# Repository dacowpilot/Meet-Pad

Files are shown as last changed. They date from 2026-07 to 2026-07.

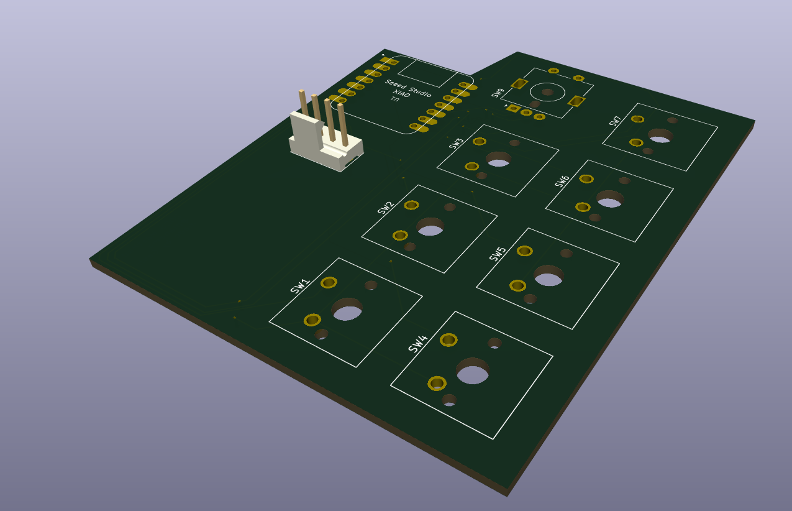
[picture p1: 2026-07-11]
Assets/PCB-3d-rendering.png

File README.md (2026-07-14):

# Meet-Pad
_com apple Pasteboard bxIFWW  
made in Shapr3D
# Features 

Meet-Pad is a hackpad that has 7 keys for shortcuts(like mute, camera, record, leave, etc.), a rotary encoder for volume control, and an OLED display screen for things like status. Like the name says, it will be used for shortcuts in meetings such as zoom calls and other meeting apps. The firmware might have a few bugs right now but I can fix it later once I get the XIAO.

# CAD

_com apple Pasteboard 4OdL4Z
_com apple Pasteboard 09b4Jj
Made in Shapr3D.

# PCB

PNG image
PNG image  

Made in KiCad.

# BOM

I already have a soldering iron so I don't need the soldering grant, but I do need the PCB and 3D printed case grant.  

Below are the parts I will be using to make my hackpad:  

• 1x XIAO RP2040  
• 7x Cherry MX Switches  
• 1x EC11 Rotary Encoder  
• 1x 0.91 inch OLED display  
• 7x White DSA Keycaps  
• 4x M3x16mm screws  
• 1x 3D printed case (1x Top Piece, 1x Bottom Piece, 1x Rotary Encoder Knob)
• 1x PCB board

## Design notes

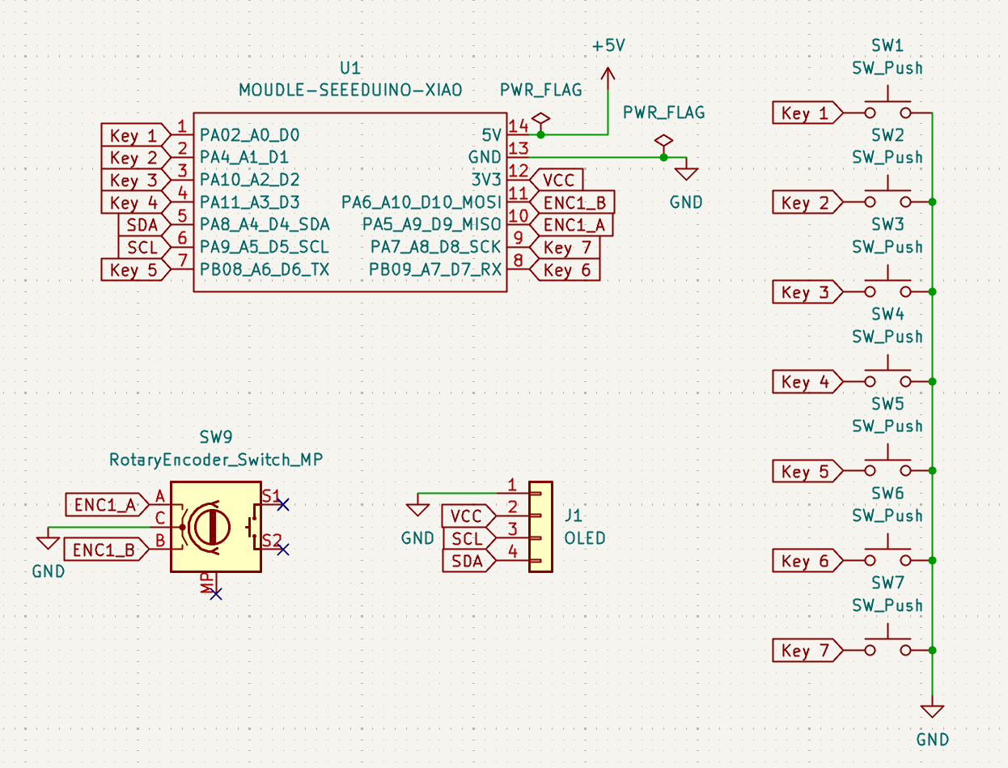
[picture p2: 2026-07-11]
Assets/schematic.png

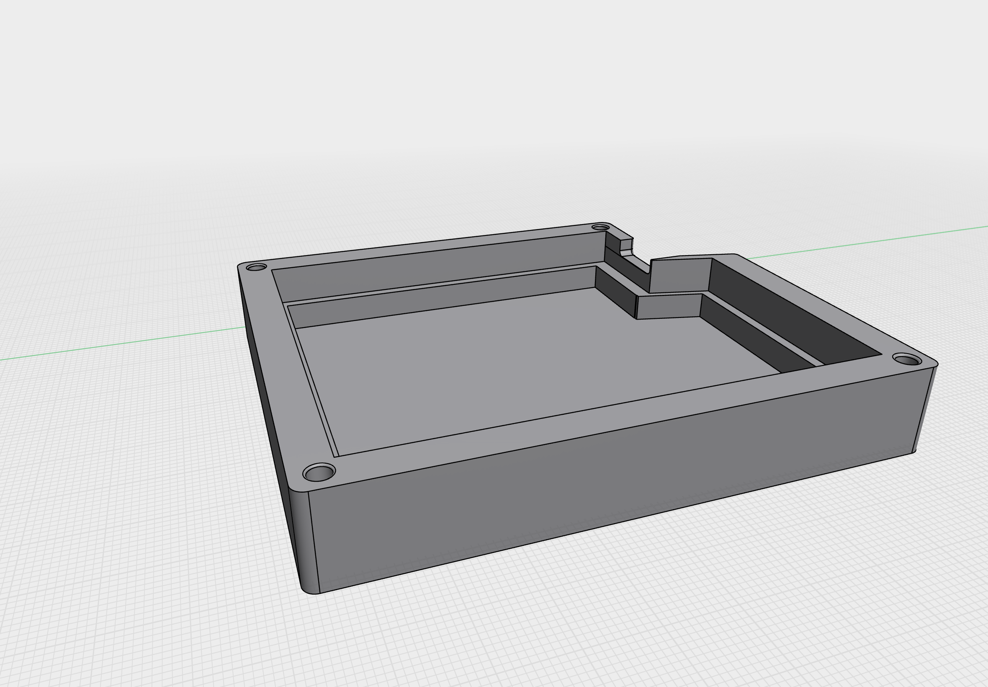
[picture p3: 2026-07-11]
Assets/case-bottom.png

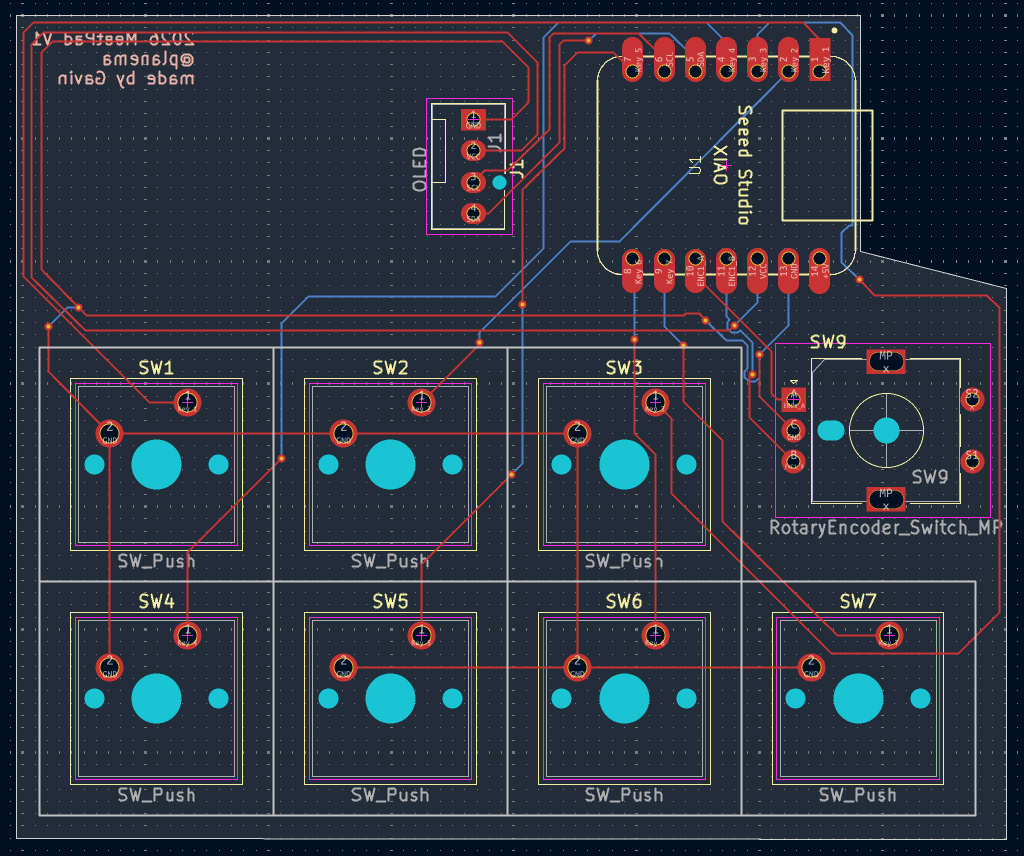
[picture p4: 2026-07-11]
Assets/PCB.png

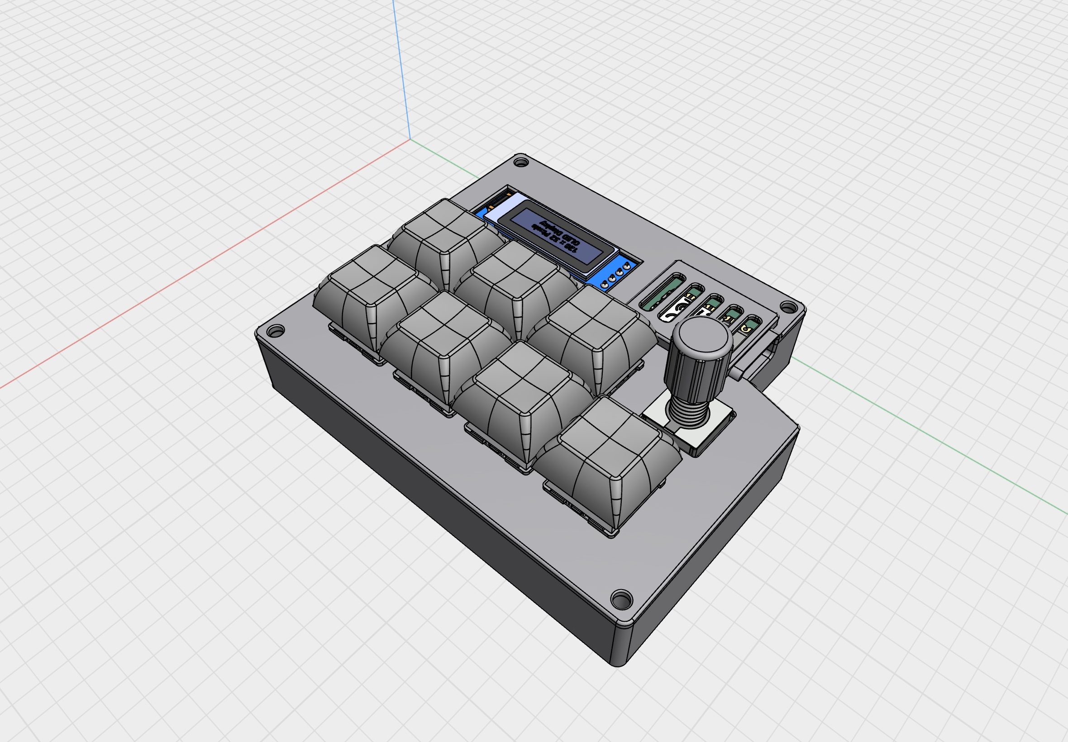
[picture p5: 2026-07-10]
Assets/Meetpad.png

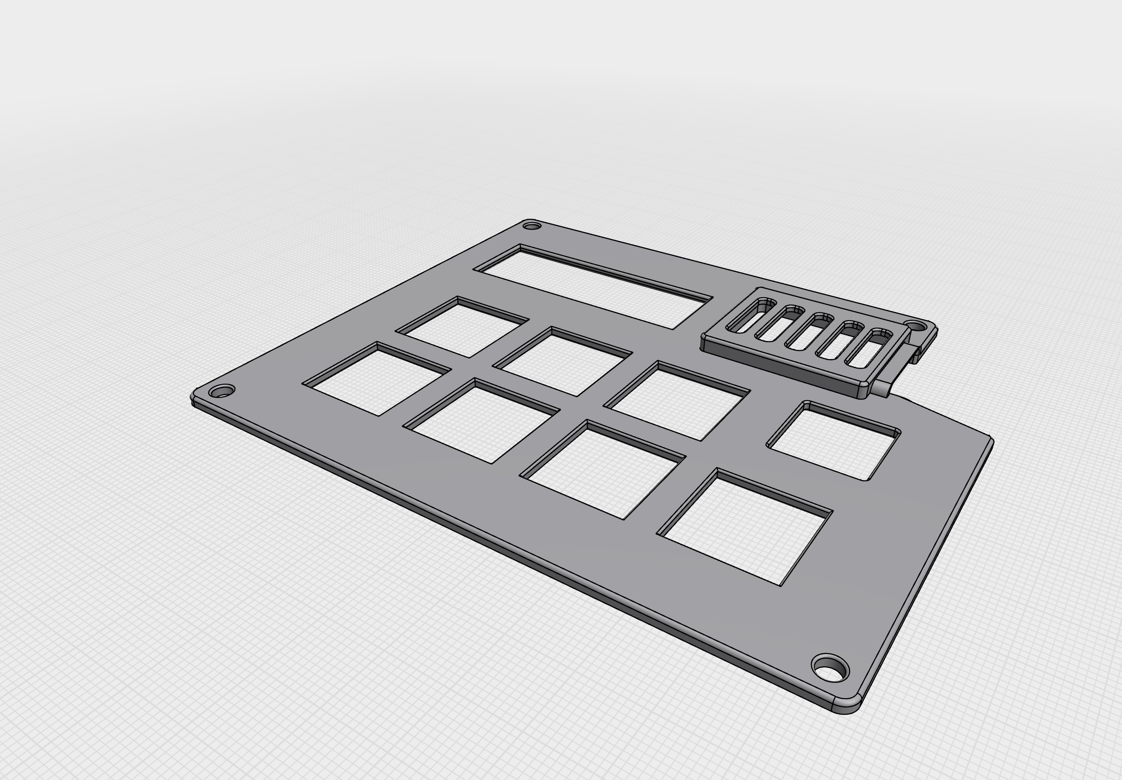
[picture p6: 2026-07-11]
Assets/top-case.png

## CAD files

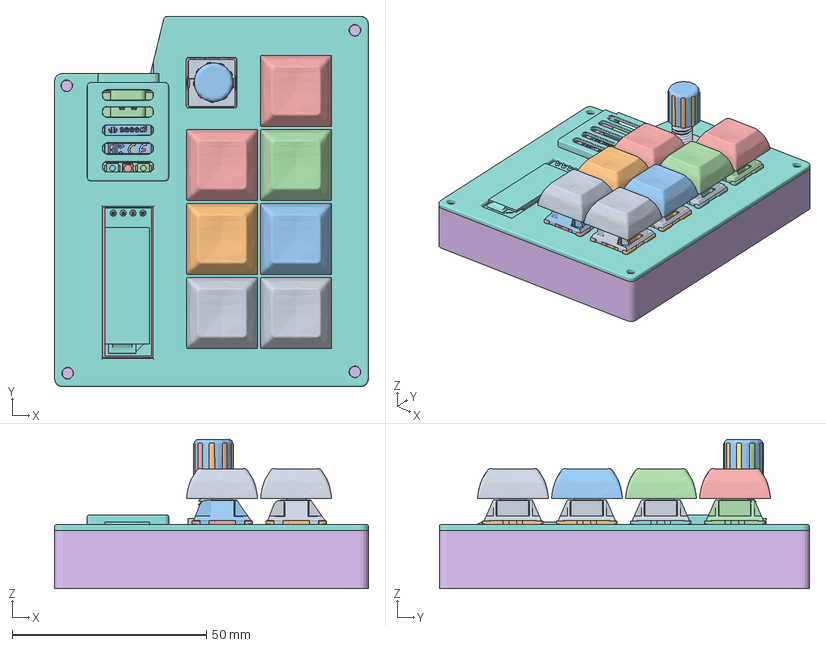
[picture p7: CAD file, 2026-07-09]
CAD/meetpad.3mf
80.8 x 95.3 x 38.4 mm
Imported_03
Imported_04_(1)
Imported_20
Imported_03_(5)
Imported_05_(2)
Imported_18
Imported_19
Imported_03_(3)
Imported_07_(4)
Imported_13
Imported_05
Imported_03_(2)
Imported_04_(4)
Imported_08
Imported_03_(1)
Imported_07
Imported_01_(4)
Imported_01
Imported_04_(4)_(2)
Imported_06_(4)
Imported_03_(4)
Imported_07_(1)
Imported_07_(4)_(2)
Imported_01_(2)
Imported_02
Imported_03_(6)
Imported_12
Imported_04
Imported_06
Imported_09
Imported_04_(3)
Imported_10
Imported_06_(3)
Imported_11
Imported_26
Imported_14
Imported_15
Imported_16
Imported_17
Imported_21
Imported_24
Imported_02_(5)
Imported_22
Imported_06_(4)_(2)
Imported_23
Imported_25
Imported_01_(3)
Imported_27
Imported_05_(4)
Imported_02_(2)
Imported_04_(2)
Imported_05_(3)
Imported_05_(5)
Imported_06_(2)
Imported_06_(2)_(2)
Imported_07_(2)
Imported_01_(1)
Imported_02_(1)
Imported_05_(1)
Imported_06_(1)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

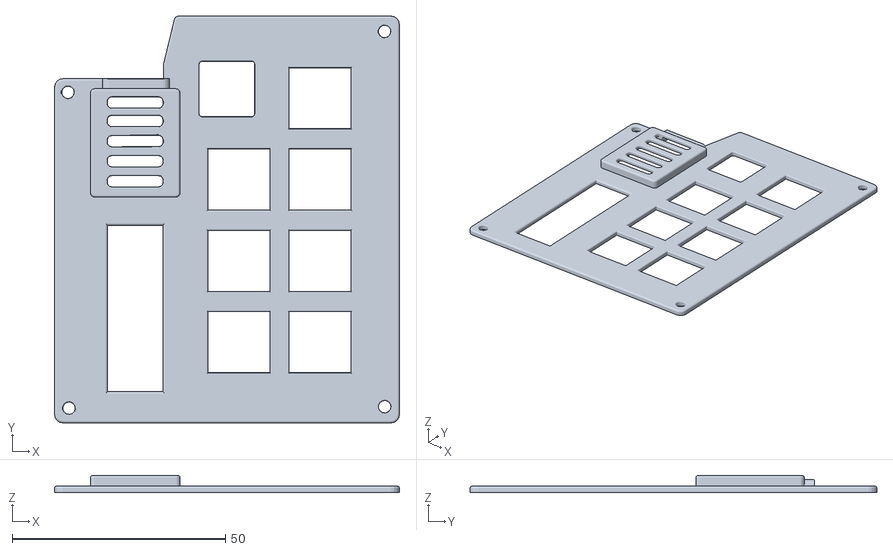
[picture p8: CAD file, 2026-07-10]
Production/case-top.stl
80.8 x 95.3 x 3.99

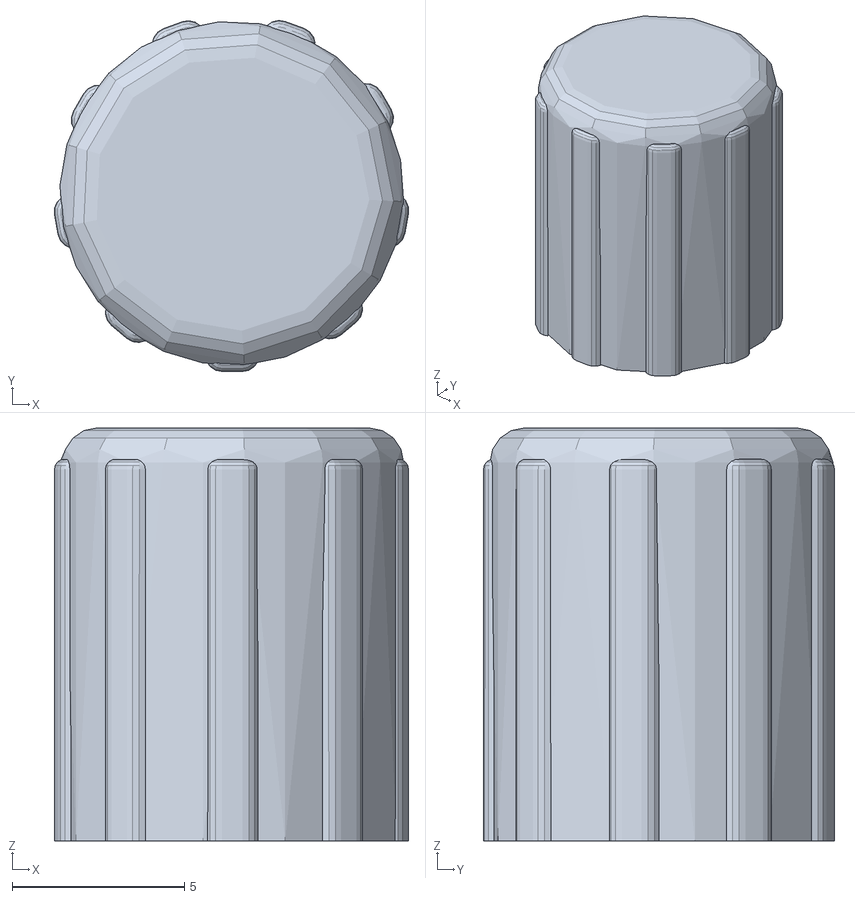
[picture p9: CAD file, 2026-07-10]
Production/rotary-encoder-knob.stl
10.3 x 10.2 x 12.0

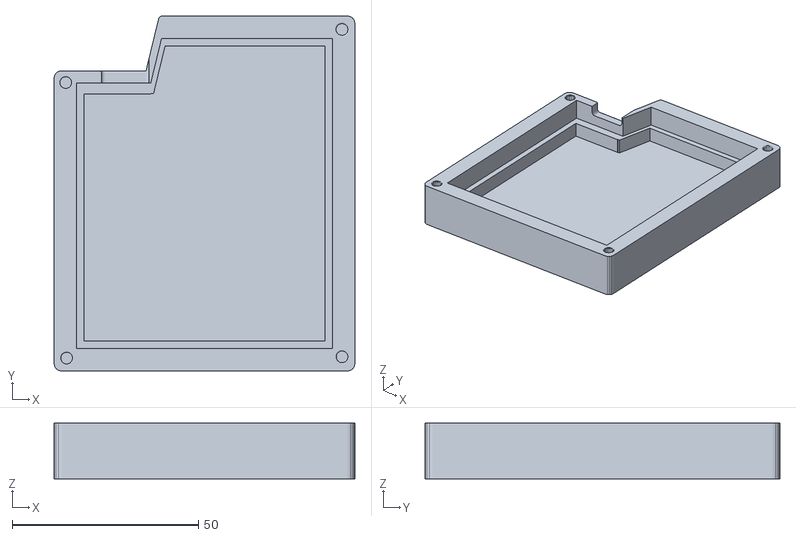
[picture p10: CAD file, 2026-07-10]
Production/case-bottom.stl
80.8 x 95.3 x 15.0

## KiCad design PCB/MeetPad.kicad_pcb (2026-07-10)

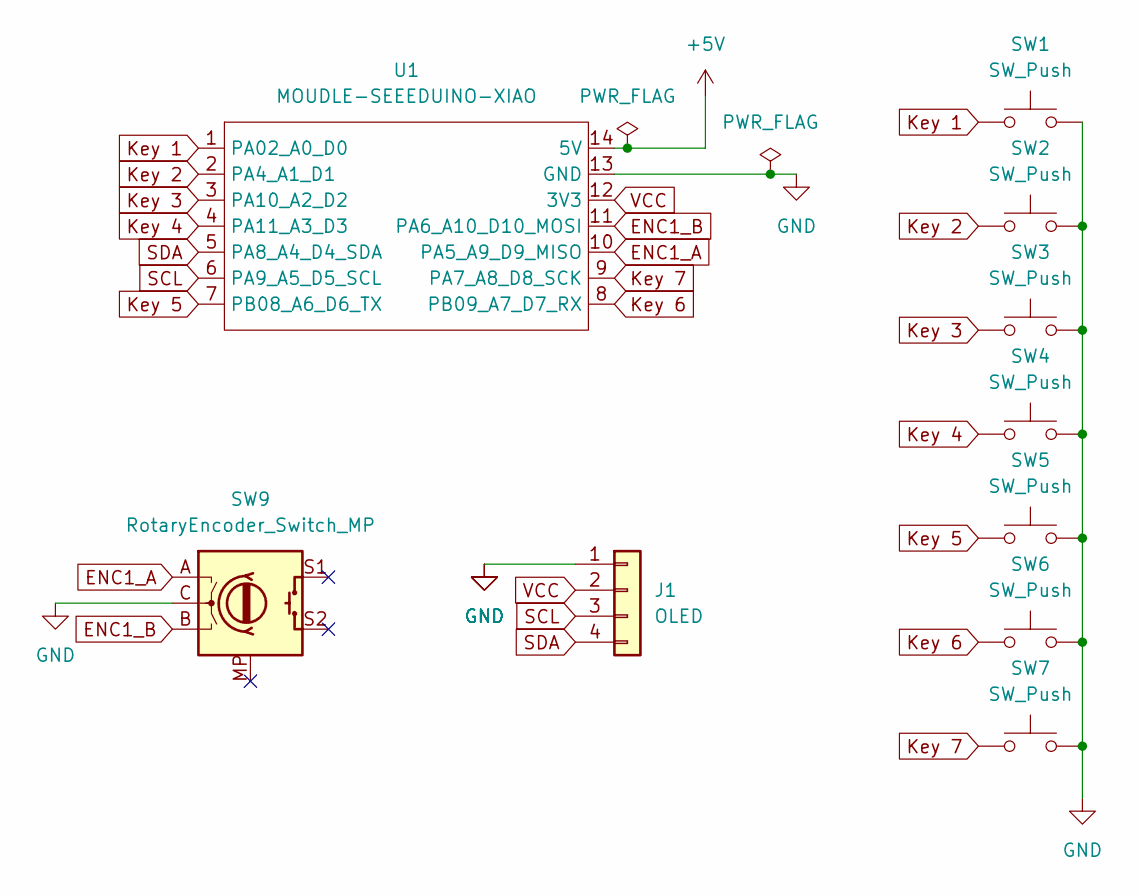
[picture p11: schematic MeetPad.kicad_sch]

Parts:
J1: OLED; FanPinHeader_1x04_P2.54mm_Vertical
SW1, SW2, SW3, SW4, SW5, SW6, SW7: SW_Push; SW_Cherry_MX_1.00u_PCB
SW9: RotaryEncoder_Switch_MP; RotaryEncoder_Alps_EC11E-Switch_Vertical_H20mm_MountingHoles
U1: MOUDLE-SEEEDUINO-XIAO; XIAO-Generic-Hybrid-14P-2.54-21X17.8MM

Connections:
+5V: U1.14 (5V)
ENC1_A: SW9.A, U1.10 (PA5_A9_D9_MISO)
ENC1_B: SW9.B, U1.11 (PA6_A10_D10_MOSI)
GND: J1.1, SW1.2, SW2.2, SW3.2, SW4.2, SW5.2, SW6.2, SW7.2, SW9.C, U1.13 (GND)
Key 1: SW1.1, U1.1 (PA02_A0_D0)
Key 2: SW2.1, U1.2 (PA4_A1_D1)
Key 3: SW3.1, U1.3 (PA10_A2_D2)
Key 4: SW4.1, U1.4 (PA11_A3_D3)
Key 5: SW5.1, U1.7 (PB08_A6_D6_TX)
Key 6: SW6.1, U1.8 (PB09_A7_D7_RX)
Key 7: SW7.1, U1.9 (PA7_A8_D8_SCK)
SCL: J1.3, U1.6 (PA9_A5_D5_SCL)
SDA: J1.4, U1.5 (PA8_A4_D4_SDA)
VCC: J1.2, U1.12 (3V3)

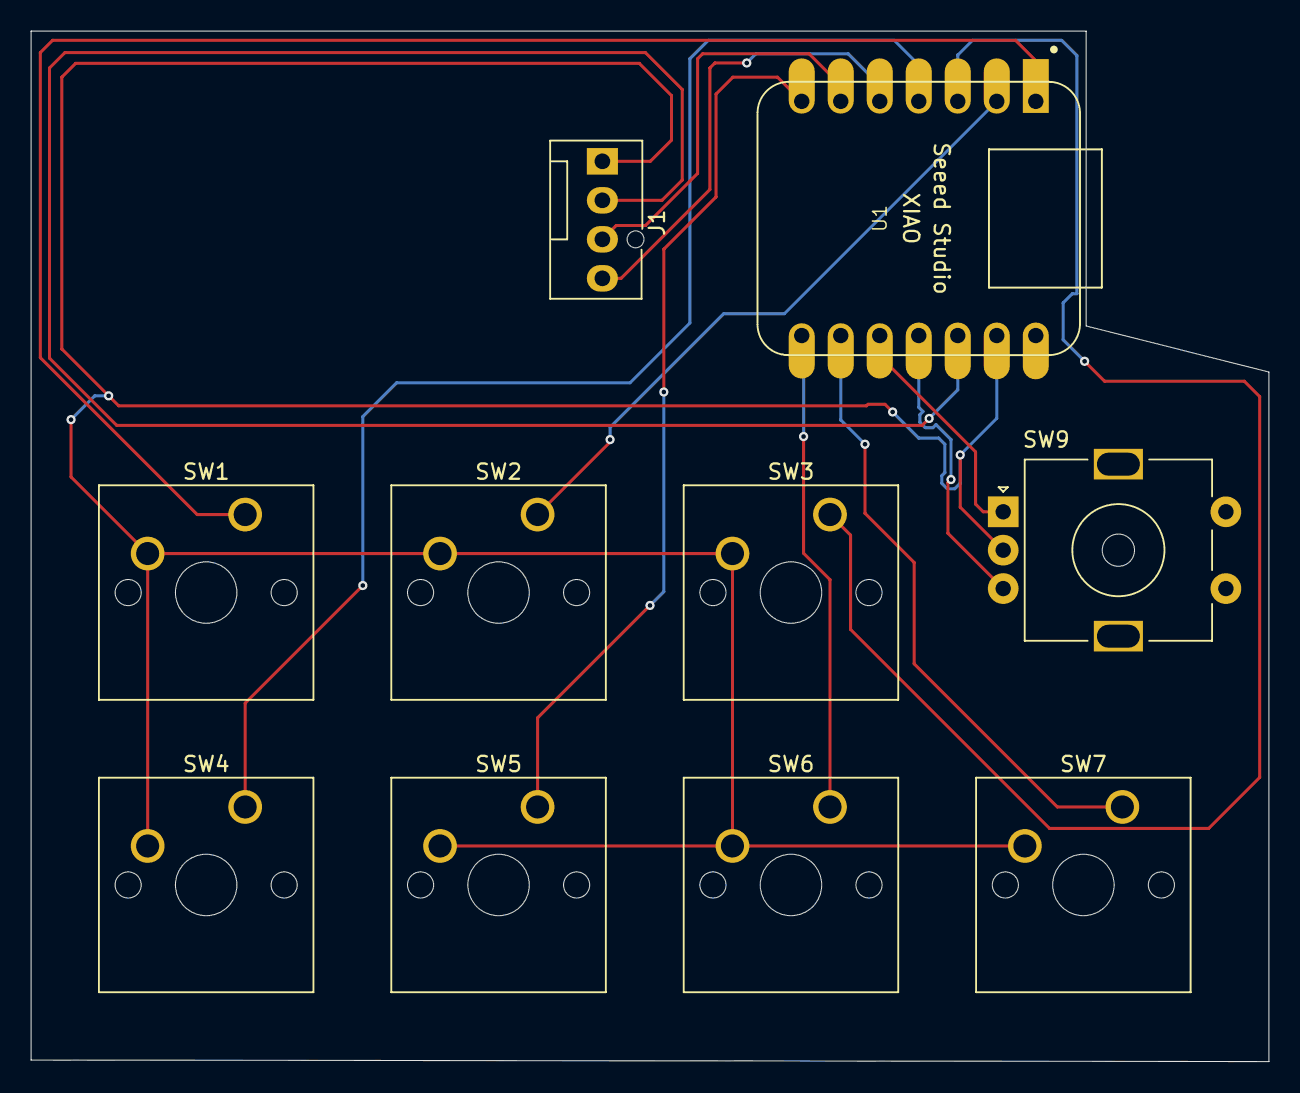
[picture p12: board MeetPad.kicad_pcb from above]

Board: 2 copper layers, 80.6 x 67.1 mm, 10 parts (0 on the bottom side), 13 nets.

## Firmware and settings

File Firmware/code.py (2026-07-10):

import board

from kmk.kmk_keyboard import KMKKeyboard
from kmk.keys import KC
from kmk.scanners.keypad import KeysScanner
from kmk.modules.encoder import EncoderHandler

from kmk.modules.display import Display
from kmk.extensions.display.ssd1306 import SSD1306

keyboard = KMKKeyboard()

encoder_handler = EncoderHandler()
keyboard.modules.append(encoder_handler)

encoder_handler.map = [
    ((KC.VOLU, KC.VOLD),)
]

encoder_handler.pins = (
    (board.D9, board.D10, None),
)

display = Display()
display.driver = SSD1306(
    width=128,
    height=64,
    i2c=board.I2C(sda=board.D4, scl=board.D5)
)

keyboard.modules.append(display)

keyboard.matrix = KeysScanner(
    pins=[
        board.D0,
        board.D1,
        board.D2,
        board.D3,
        board.D6,
        board.D7,
        board.D8,
    ],
    value_when_pressed=False,
    pull=True
)

keyboard.keymap = [
    [
        KC.LALT(KC.A),
        KC.LALT(KC.V),
        KC.LALT(KC.Y),
        KC.LALT(KC.H),
        KC.LALT(KC.SHIFT(KC.S)),
        KC.NO,
        KC.NO,
    ]
]

if __name__ == "__main__":
    keyboard.go()

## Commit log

2026-07-10 added PCB
    [MeetPad.kicad_pcb, MeetPad.kicad_sch]
2026-07-10 Create PCB
2026-07-10 Create …
2026-07-10 Added production files
    [case-bottom.stl, case-top.stl, rotary-encoder-knob.stl]
